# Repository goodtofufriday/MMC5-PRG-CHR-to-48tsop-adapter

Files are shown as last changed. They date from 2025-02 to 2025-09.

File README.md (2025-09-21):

*BOARDS NEED TO HAVE GROUND PLANE ADDED TO THEM FOR STABILITY! They work but after even a few minutes crash, consensus is due to lack of ground plane. Will update when i have time.*

THIS IS NOW IN TESTING! Only the piggyback version has been updated to include a ground plane and larger bridging pads.

This project is for the NES / Famicom to be able to use flash chips for translations or replace dead roms. Also sram.

Everything created in eagle. Feel free to use with credit.

Piggyback version included. You need to pull chip enable and connect to 5v to disable the rom.

MMC5 / PRG / CHR to 48TSOP Flash Adatper

Replace roms with this board. Use 5v 8megabit flash

Below are instructions for the multi-board adapter. You can use this even for 28 pin rom boards.

Place on back of rom. Pull rom CE/OE + pull high 

Bridge Pin1 and 3 for all EXCEPT 128kb chr or Nrom boards

MMC5: Bridge all six circled jumpers

CHR: Bridge 3rd Circle + 1st square for 256kb

PRG: Bridge 1st Circle + 2nd square for 512kb or Top pads for 256kb

Also included is a ram adapter for romhacks like megaman minus inifinity. use ram IS61C256AL

Oshpark links: 

Piggyback ver. https://oshpark.com/shared_projects/Uz4v9Vq7

Ram adapter https://oshpark.com/shared_projects/bVWn1u0x

MMC5 only ver. https://oshpark.com/shared_projects/fcmApdiZ

Special thanks to https://github.com/techav-homebrew/LCC32-DIP32-Flash-Adapter for saving me some time on the 32pin board. Everything else is custom, hence the included libraries.

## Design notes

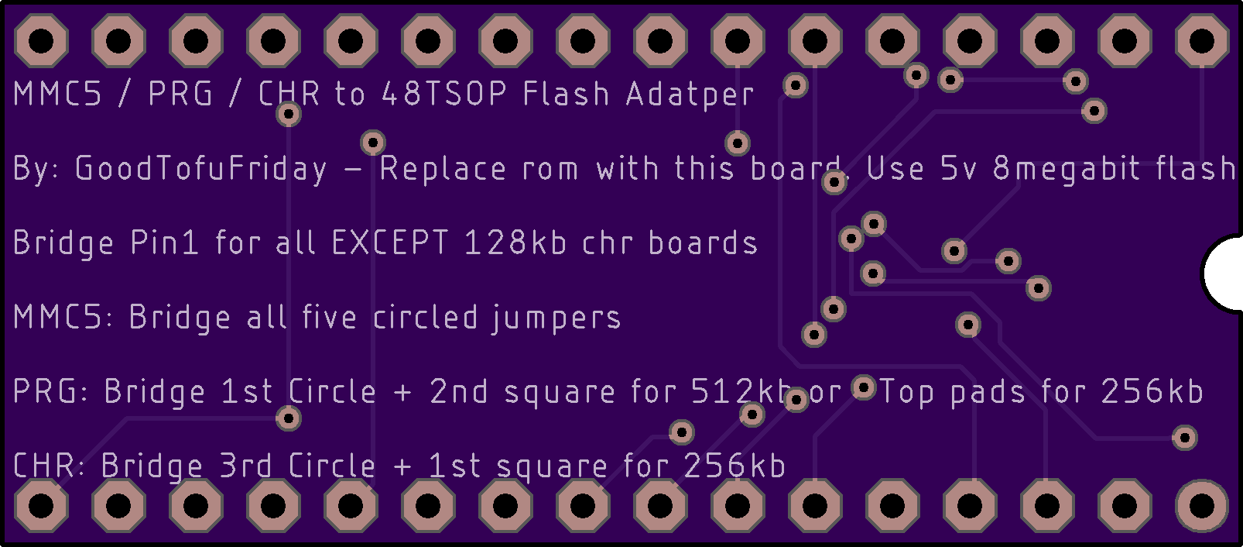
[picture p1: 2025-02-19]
back.png

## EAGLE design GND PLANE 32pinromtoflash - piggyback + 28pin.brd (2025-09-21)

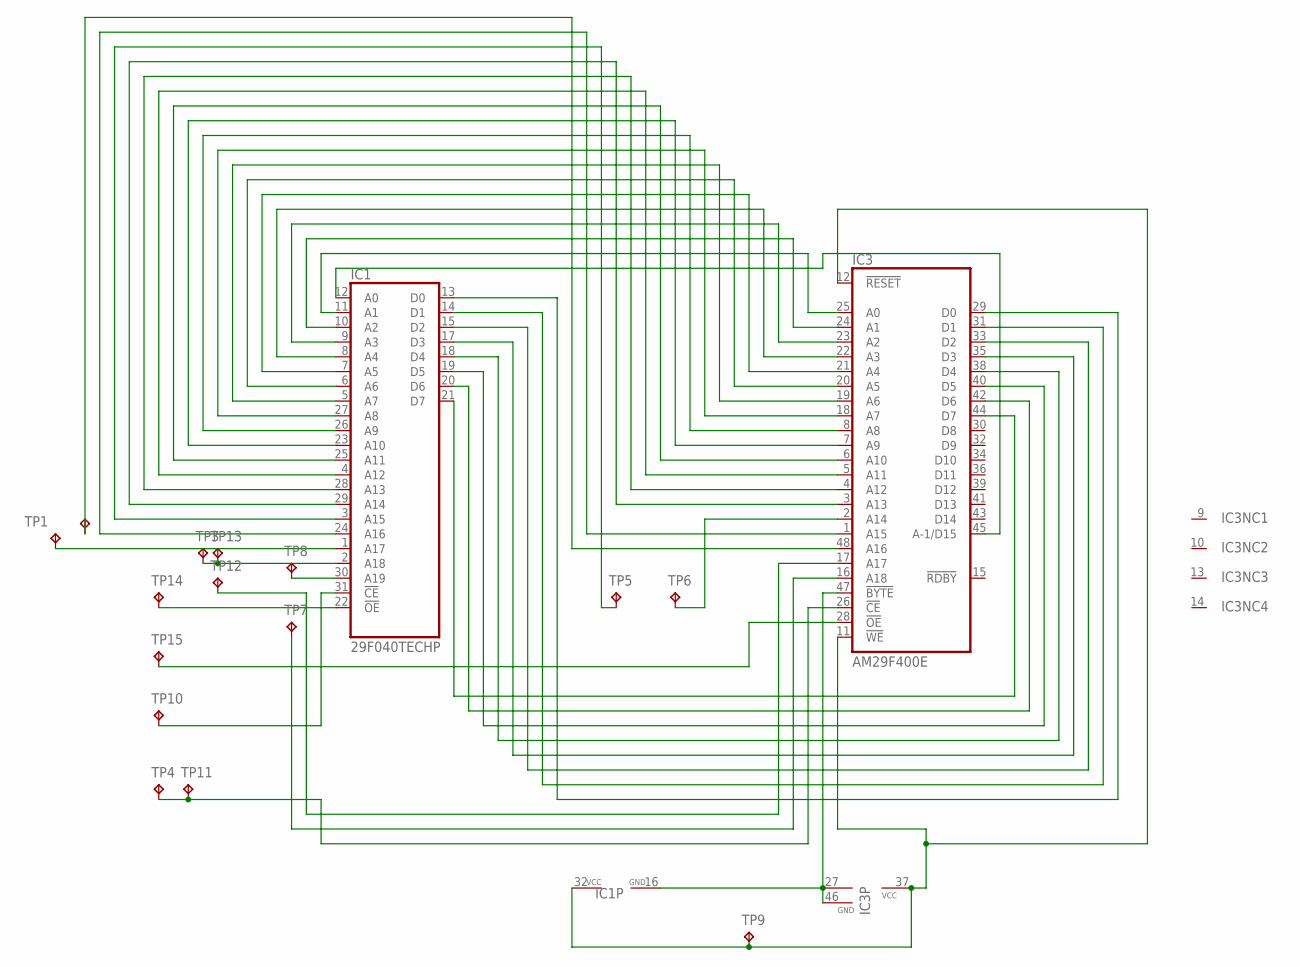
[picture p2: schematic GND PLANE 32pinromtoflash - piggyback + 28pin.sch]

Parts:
IC1: 29F040TECHP; DIL32-3
IC3: AM29F400E; TSOP48
TP1, TP2, TP3, TP4, TP5, TP6, TP7, TP8, TP9, TP10, TP11, TP12, TP13, TP14, TP15: TPTP15SQ; TP15SQ

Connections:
A14FLASH: IC3.2 (A14), TP6.TP
A17FLASH: IC3.17 (A17), TP12.TP
A17PIN1ROM: IC1.1 (A17), TP1.TP
A18FLASH: IC3.48 (A16), TP2.TP
CEFLASH: IC3.26 (!CE), TP4.TP, TP11.TP
CEROMPIN31: IC1.31 (!CE), TP10.TP
FLASH-A18: IC3.16 (A18), TP7.TP
MMC5-A0: IC1.12 (A0), IC3.45 (A-1/D15)
MMC5-A1: IC1.11 (A1), IC3.25 (A0)
MMC5-A2: IC1.10 (A2), IC3.24 (A1)
MMC5-A3: IC1.9 (A3), IC3.23 (A2)
MMC5-A4: IC1.8 (A4), IC3.22 (A3)
MMC5-A5: IC1.7 (A5), IC3.21 (A4)
MMC5-A6: IC1.6 (A6), IC3.20 (A5)
MMC5-A7: IC1.5 (A7), IC3.19 (A6)
MMC5-A8: IC1.27 (A8), IC3.18 (A7)
MMC5-A9: IC1.26 (A9), IC3.8 (A8)
MMC5-A10: IC1.23 (A10), IC3.7 (A9)
MMC5-A11: IC1.25 (A11), IC3.6 (A10)
MMC5-A12: IC1.4 (A12), IC3.5 (A11)
MMC5-A13: IC1.28 (A13), IC3.4 (A12)
MMC5-A14: IC1.29 (A14), IC3.3 (A13)
MMC5-A15: IC1.3 (A15), TP5.TP
MMC5-A16: IC1.24 (A16), IC3.1 (A15)
MMC5-A19: IC1.30 (A19), TP8.TP
MMC5-D0: IC1.13 (D0), IC3.29 (D0)
MMC5-D1: IC1.14 (D1), IC3.31 (D1)
MMC5-D2: IC1.15 (D2), IC3.33 (D2)
MMC5-D3: IC1.17 (D3), IC3.35 (D3)
MMC5-D4: IC1.18 (D4), IC3.38 (D4)
MMC5-D5: IC1.19 (D5), IC3.40 (D5)
MMC5-D6: IC1.20 (D6), IC3.42 (D6)
MMC5-D7: IC1.21 (D7), IC3.44 (D7)
MMC5-VCC: IC1.32 (VCC), IC3.11 (!WE), IC3.12 (!RESET), IC3.37 (VCC), TP9.TP
MMC5-VSS: IC1.16 (GND), IC3.27 (GND), IC3.46 (GND), IC3.47 (!BYTE)
OEFLASH: IC3.28 (!OE), TP15.TP
PIN2ROM: IC1.2 (A18), TP3.TP, TP13.TP
PIN22ROM: IC1.22 (!OE), TP14.TP

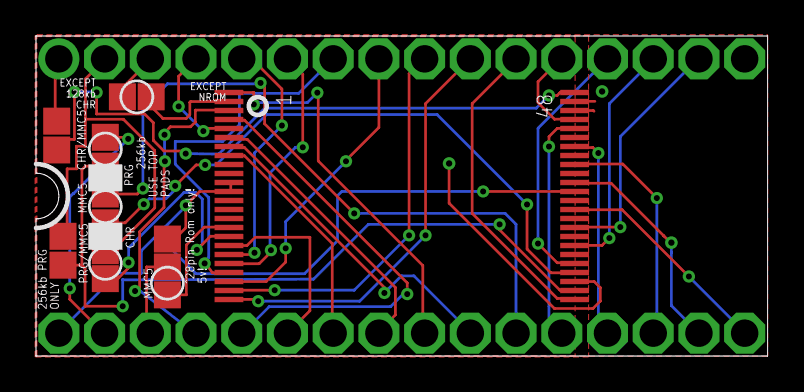
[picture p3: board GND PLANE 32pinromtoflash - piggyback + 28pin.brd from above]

Board: 2 copper layers, 40.6 x 17.8 mm, 17 parts (1 on the bottom side), 38 nets.

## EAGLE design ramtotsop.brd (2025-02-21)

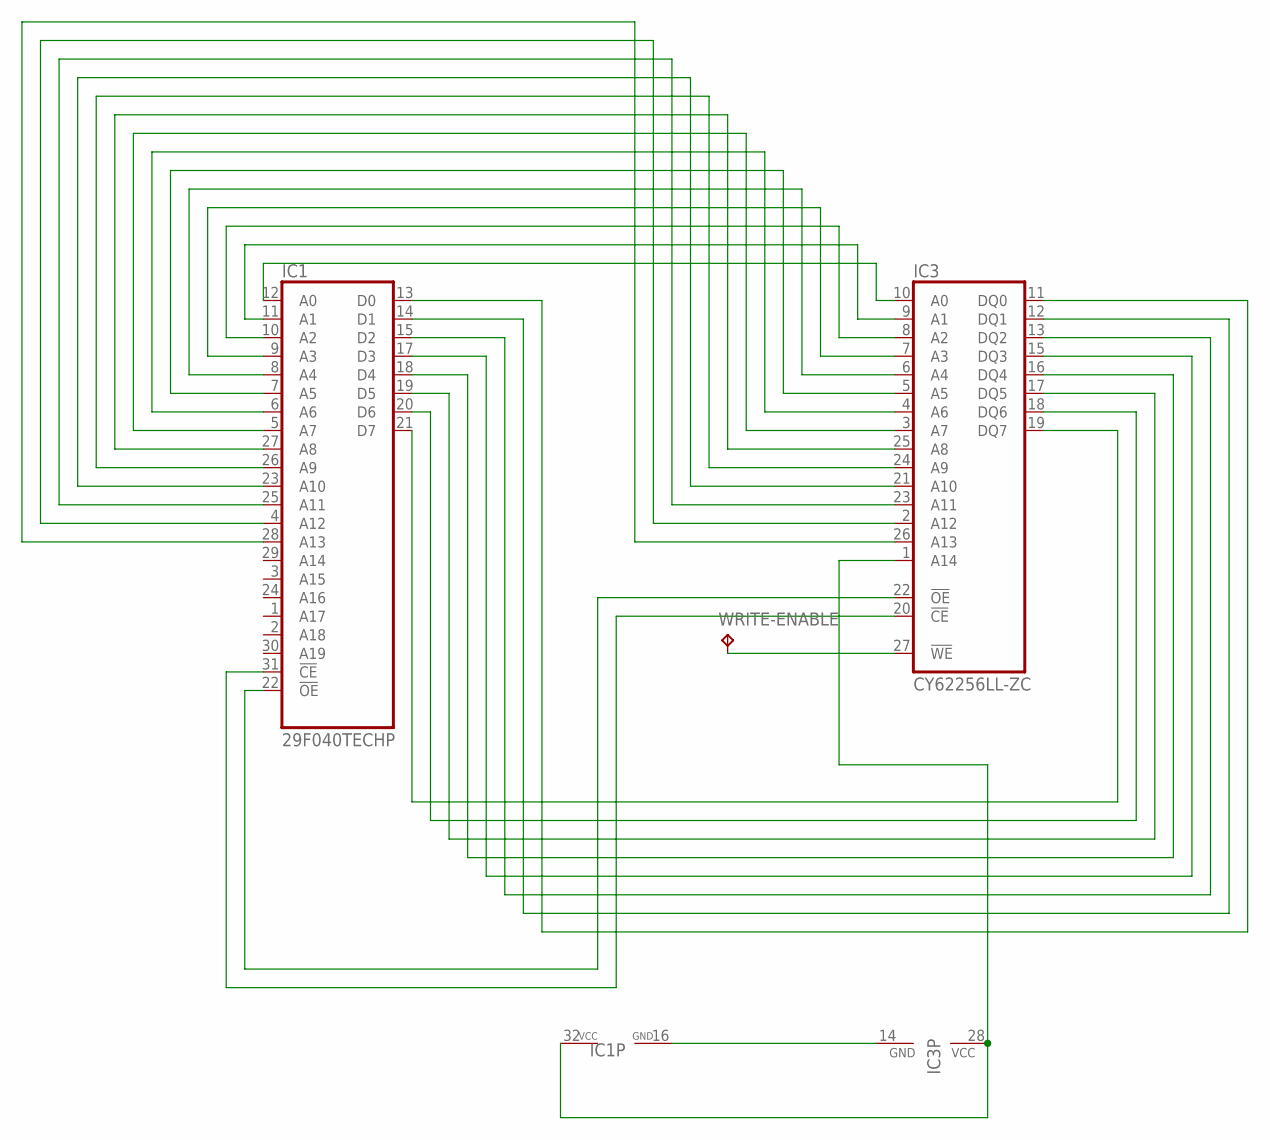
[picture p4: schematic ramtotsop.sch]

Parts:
IC1: 29F040TECHP; DIL32-3
IC3: CY62256LL-ZC; TSOP1-28
WRITE-ENABLE: TPTP20SQ; TP20SQ

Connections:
CEROMPIN31: IC1.31 (!CE), IC3.20 (!CE)
MMC5-A0: IC1.12 (A0), IC3.10 (A0)
MMC5-A1: IC1.11 (A1), IC3.9 (A1)
MMC5-A2: IC1.10 (A2), IC3.8 (A2)
MMC5-A3: IC1.9 (A3), IC3.7 (A3)
MMC5-A4: IC1.8 (A4), IC3.6 (A4)
MMC5-A5: IC1.7 (A5), IC3.5 (A5)
MMC5-A6: IC1.6 (A6), IC3.4 (A6)
MMC5-A7: IC1.5 (A7), IC3.3 (A7)
MMC5-A8: IC1.27 (A8), IC3.25 (A8)
MMC5-A9: IC1.26 (A9), IC3.24 (A9)
MMC5-A10: IC1.23 (A10), IC3.21 (A10)
MMC5-A11: IC1.25 (A11), IC3.23 (A11)
MMC5-A12: IC1.4 (A12), IC3.2 (A12)
MMC5-A13: IC1.28 (A13), IC3.26 (A13)
MMC5-D0: IC1.13 (D0), IC3.11 (DQ0)
MMC5-D1: IC1.14 (D1), IC3.12 (DQ1)
MMC5-D2: IC1.15 (D2), IC3.13 (DQ2)
MMC5-D3: IC1.17 (D3), IC3.15 (DQ3)
MMC5-D4: IC1.18 (D4), IC3.16 (DQ4)
MMC5-D5: IC1.19 (D5), IC3.17 (DQ5)
MMC5-D6: IC1.20 (D6), IC3.18 (DQ6)
MMC5-D7: IC1.21 (D7), IC3.19 (DQ7)
MMC5-VCC: IC1.32 (VCC), IC3.1 (A14), IC3.28 (VCC)
MMC5-VSS: IC1.16 (GND), IC3.14 (GND)
unnamed: IC1.22 (!OE), IC3.22 (!OE)
WRITE-ENABLE: IC3.27 (!WE), WRITE-ENABLE.TP

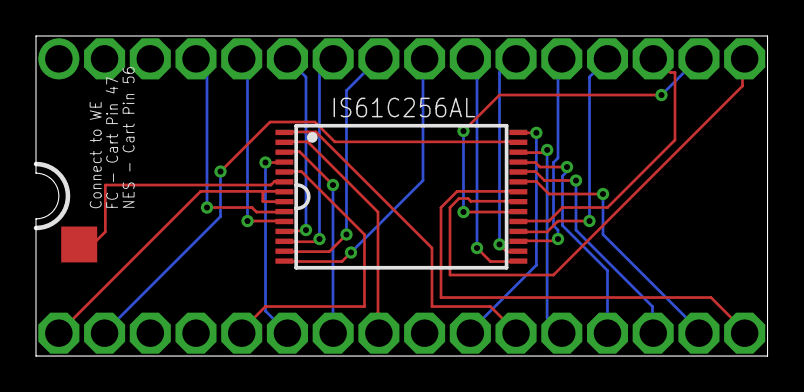
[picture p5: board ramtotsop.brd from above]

Board: 2 copper layers, 40.6 x 17.8 mm, 3 parts (1 on the bottom side), 27 nets.
